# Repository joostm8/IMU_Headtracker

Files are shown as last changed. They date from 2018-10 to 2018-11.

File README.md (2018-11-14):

# IMU_Headtracker
## Preface
I wanted to use a headtracker to use in racing games such as Dirt Rally or RaceRoom Racing Experience. TrackIR is the best known tracker, but I couldn't really justify the cost. Having seen many other IMU-based headtracker projects, I figured this was a neat little project to work on in my spare time, since most of the heavy lifting work has already been done by other people:
- The IMU sensorfusion algorithm to translate accelerometer, gyroscope and magnetometer data into yaw, pitch and roll was made by Sebastian Madgwick and is available as C code:http://x-io.co.uk/open-source-imu-and-ahrs-algorithms/ .
- Opentrack is a project that can translate any joystick/gamepad information into freetrack data, used by games to do headtracking. Opentrack also provides centering support, and allows you to invert axis on-the-fly.

I really wanted no extra wiring, so I preferably wanted a Bluetooth dongle or something alike, such that I could treat the headtracker as a standalone little box.

## Hardware components
What was left to do for me was to use a microcontroller, an MPU and a Bluetooth dongle that runs a game controller HID profile, in order to relay the yaw, pitch and roll data to Opentrack in a standardised manner. I chose the following components:
- IMU: an Invensense MPU9250, this is the cheapest 9 DOF IMU I could readily find on ebay, it's usage is also thoroughly documented by Kris Winer on https://github.com/kriswiner/MPU9250 .
- Microcontroller: an Atmega328p running at 3.3V and 8MHz, more specifically as a Pro-Mini Arduino clone. It is a cheap microcontroller, readily available, comes with an Arduino bootloader so I don't need an AVR programmer and as documented in https://github.com/kriswiner/MPU9250 is just about able to run the MadgwickAHRS algorithm at an okay pace.
- Bluetooth module: an RN42 is the most easily available bluetooth module with HID gamepad support, but one can also flash the RN42 firmware on the even more broadly available HC-05 modules. Refer to this link for more information: https://mitxela.com/projects/bluetooth_hid_gamepad
- Power: a small 600 mAh LiPo battery and TC4056A charger board complete the list of required hardware.
- Two LEDs to give some feedback
- An ON-OFF switch (ON-ON also works)
- Two 680 ohm resistors to limit current to the LEDs

## Software components
I needed I2C communication to communicate with the MPU9250 (SPI is also possible), UART communication to communicate with the HC-05 and I needed to alter the MadgwickAHRS algorithm slightly.
- I2C communication is handled by an I2C library provided by Microchip: https://www.microchip.com/wwwAppNotes/AppNotes.aspx?appnote=en591794 (search for AN2480 in case the link doesn't work).
- The MadgwickAHRS algorithm normally expects to be run at a certain frequency, however the Atmega328p can't reliably run it at very high frequencies. Instead, I opted to alter the library, as demonstrated in this code from Michael Baker https://github.com/mikeshub/Pololu_Open_IMU, so it now calculates the time delta (dt) between the current start and the previous start of the code section of the AHRS algorithm, so it can basically run at the highest speed possible.
- UART to communicate with the HC-05: At 8 MHz clockspeed, 38400 baud is the highest baudrate that lies within the recommended clock error range, as stated in the Atmega328p manual. Since I need almost all cpu cycles to run the AHRS algorithm, I wrote a small UART transmit function that can handle one transmission in an unblocking fashion, such that I can transmit the yaw, roll and pitch to the Bluetooth dongle, while the AHRS algorithm continues executing.

## Wiring it all up:
A small table showing how I wired the components. Note that I relied on the LDO of the Pro-Mini to regulate the voltage for all parts. According to some datasheet on an Aliexpress like site, the part should provide at least 100 mA, whilst all components together will use approximately 60 mA, so this should be fine.

Note that I inserted an ON-OFF switch on the OUT+ line of the TC4056A, but this is not shown in the table.

**Note that the resistors aren't listed in the table, but PIN7 must be connected to the LED1 Anode through a 680 ohm resistor (likewise for PIN6 and LED2 Anode)!!**

| Pro-Mini | HC-05 | MPU9250 | TC4056A | LED1 | LED2 |
| --- | --- | --- | --- | --- | --- |
| SDA | | SDA | | | |
| SCL | | SCL | | | |
| TX | RX | | | | |
| RX | TX | | | | |
| PIN 7 | | | | Anode | |
| PIN 6 | | | | | Anode |
| RAW | | | OUT + | | |
| VCC (3.3V) | 3.3V in | 3.3V in | | | |
| GND | GND | GND | OUT - | Cathode | Cathode |

## 3D printable box
I've provided some STL files for a small 3D printable box that can mount the different components. The HC-05 I used was mounted on the standard blue breakout PCB, the MPU9250 is one of those modules mounted on the purple PCB. You'll have to stack the PCBs using pin headers, with a double layer of black spacers to achieve the correct spacing. On the HC-05, the TX, RX and GND pins match up, and on the MPU-9250 the SDA and SCL pins match up (granted you mount it **upside down**). Other pins can be connected with some servo wire. Note to self: provide a picture, that will be clearer.

## Some more remarks
### Application specific tips
- The Invense MPU9250 has built-in accelerometer calibration registers, however, even with their provided code (MPU Hardware Offset Registers Application Note) I could not get this to work correctly, therefore I did the accelerometer offsets in software. Gyroscope offset registers works fine.
- The more readily available RN42 manual has an incorrect specification of the joystick gamepad report format. Instead just use the format as described in https://mitxela.com/projects/bluetooth_hid_gamepad.
- The MadgwickAHRS algorithm does not care about the unit of the magnetometer and accelerometer readings, so don't waste computing time converting those readings to the correct unit. The gyroscope inputs do expect an input in radians per second.
- One might notice how there is some sign inversion happening on the input of the AHRS algorithm, that's because I mounted the MPU9250 upside down in the box.
- The LEDs help when starting the headtracker. When the LED on PIN7 goes on, you must place the headtracker on a flat surface, because it calculates the acceleromter and gyroscope offsets. When the LED on PIN6 goes on, you must wave the headtracker in a 8 shaped motion to calibrate the magnetometer (like you would do with your cellphone).
- The uploaded code is an Atmel Studio project, but a flashable hex file can be found in the Debug folder. One can flash with the command: `avrdude -c arduino -p atmega328p -P COM# -b 57800 -U flash:w:IMU_Headtracker.hex:i` Where `COM#`must be replaced with the id of your serial device (e.g. COM10), note that in linux this will be a `/dev/ttyS#`

### General debugging tips
If you want to attempt an IMU-headtracker project yourself, you might bump into some issues. In that case a debugger is your best friend, or if you don't have a debugger, a UART serial connection with some debug info is your best friend, however, do ensure you format your serial printouts correctly!
- an *int32_t* is defined as "signed long int" in stdint.h, so to print a correctly formatted string, use *%ld*
- float (*%f*) formatting is not supported by the AVR-libc *sprintf* function, therefore you must first use *dtostrf* , then use *strcat* to obtain a printout of a floating point number.

## License
The provided code is licensed under the GPLv3 license. The Microchip TWI library retains its own license.

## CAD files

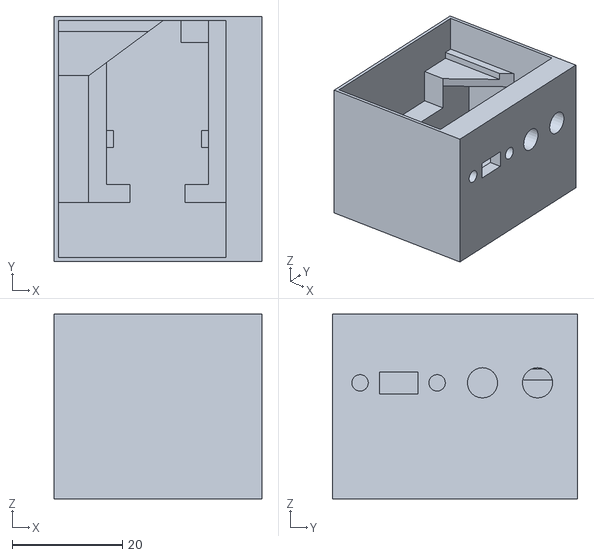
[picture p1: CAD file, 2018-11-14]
STL_files/headtracker_box.stl
37.8 x 44.6 x 33.6

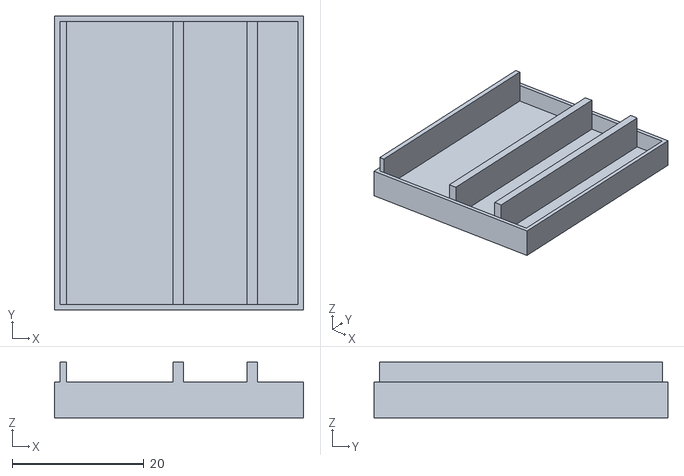
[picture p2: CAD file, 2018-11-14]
STL_files/headtracker_box_top_piece.stl
37.8 x 44.6 x 8.50

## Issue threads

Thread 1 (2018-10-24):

Add status LED functionality

joostm8, 2018-10-24:
With no serial monitor to view when you have to put down to device for calibration it would be nice to have some status LED's that indicate the calibration status instead. This way you also know when to start waving an 8 shape when calibrating the magnetometer.

joostm8, 2018-11-14:
Functionality added through pins 6 and 7

Closed 2018-11-14.

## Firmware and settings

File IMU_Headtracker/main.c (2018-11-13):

/*
 * IMU_Headtracker.c
 *
 * Created: 1/08/2018 20:43:46
 * Author : Joost
 *
 * IMU headtracker
 * Requires:
 * MPU9250
 * Atmega328p
 * rn42 (or hc05 flashed as rn42)
 * 
 */ 

/****************************************************************************
Macros
****************************************************************************/
#define MPU_9250_Addr 0b1101000 // 7 bit I2C address with AD0 pin to ground
#define AK8963_addr 0x0C // 7 bit magnetometer address
#define GYROSCOPE_RES_RPS 0.0005321125 // rps/lsb

// Timer 1 (16 bit) will be set to increment at rate of 1 µs
// this macro therefore allows for time deltas of up to 65 ms to be measured.
#define micros() TCNT1 

/****************************************************************************
Includes
****************************************************************************/
#include <avr/io.h>
#include <avr/interrupt.h>
#include <avr/sleep.h>
#include <util/delay.h>
#include <string.h>
#include <stdio.h>
#include <stdlib.h>
#include <stdint.h>
#include "TWI_Master.h"
#include "UART_transceiver.h"
#include "MadgwickAHRS.h"

/****************************************************************************
Variables
****************************************************************************/
static int16_t hard_iron_correction[3] = {0, 0, 0}; //x, y, z hard iron corrections, subtract from scaled measurements
// also see https://github.com/kriswiner/MPU6050/wiki/Simple-and-Effective-Magnetometer-Calibration
// precomputed magnetometer scale * soft iron
static float scale_times_soft_iron[3] = {0, 0, 0};
static uint8_t magneto_sens_adjust[3] = {0, 0, 0}; // x, y, z sens adjust values
static int16_t accelerometer_offset[3] = {0, 0, 0}; // accelerometer offsets to handle offsetting in SW.

// extern variables used in by MahonyAHRS
extern volatile float roll, pitch, yaw;
extern volatile float dt;	
extern volatile float q0, q1, q2, q3;

static uint8_t BT_command[8] = {0xFD, 0x06, 0x00, 0x00, 0x00, 0x00, 0x00, 0x00}; // BT command for HID game controller
static uint8_t send_BT_cmd = 0; // true/false when BT_cmd may be transmitted to BT chip

/****************************************************************************
  Function declarations
****************************************************************************/
void MPU_9250_initialise();
void calibrate_accelerometer();
void set_gyro_bias(int16_t*);
void calibrate_gyroscope();
void calibrate_magnetometer();
void get_magnetometer_scale();
uint8_t read_magnetometer(int16_t*);
void scale_magnetometer(float*);
void read_accelerometer_data(int16_t*);
void read_gyroscope_data(int16_t*);
void apply_magnetometer_scaling(int16_t*, float*);
void apply_accelerometer_offset(int16_t*);
void GPIO_setup_for_timing();
void GPIO_initialise();
void TIMER_setup();

/****************************************************************************
  Main code
****************************************************************************/

int main(void)
{
	
	// Start I2C interface using provided library by microchip
	// in TWI_Master.h, TWI_TWBR is set as 0x02, which yields 400kHz on 8MHz µC
	TWI_Master_Initialise();
		
	// Initialise UART at 38.4kbaud, the highest baudrate given F_CPU = 8 MHz
	UART_initialise();
	
	// Initialise LED GPIO
	GPIO_initialise();
	
	// enable global interrupts such that the I2C and UART interfaces can operate
	sei();

	_delay_ms(1000);
	
	// Initialise and calibrate MPU9250;
	MPU_9250_initialise();
	
	// Turn on pin 7, indicates to user to put the device on a flat surface
	PORTD |= 1 << PORTD7;
	
	_delay_ms(3000); // 3 second delay for user to put the device down.
	
	// Calibrate accelerometer;
	calibrate_accelerometer();
	
	// Calibrate gyroscope
	calibrate_gyroscope();
	
	// Turn off pin 7 LED
	PORTD &= ~(1 << PORTD7);
	// Turn on pin 6 LED, indicates to start waving 8 pattern
	PORTD |= 1 << PORTD6;
	
	_delay_ms(1000); // 1 sec delay for user response time.
	
	// calibrate magnetometer	
	get_magnetometer_scale();
	
	calibrate_magnetometer();
	
	// turn off LED, so user can stop waving
	PORTD &= ~(1 << PORTD6);

	//gyro is by now set to 1000 dps, which is ok
	//magneto is also set in +- 4g so we can move on to main program
	
	// Init Bluetooth controller (if needed)
	float magnetometer_data_float[3];
	float gyroscope_data_rps[3];
	int16_t magnetometer_data_raw[3];
	int16_t gyroscope_data_raw[3];
	int16_t accelerometer_data[3];
	TIMER_setup();
	GPIO_setup_for_timing();
	
	uint16_t start = micros();
	uint16_t stop = 0;
	uint8_t overflow = 0;
	
	// algorithm will run as fast as possible.
    while (1) 
    {
			PORTB |= 1<<PORTB1;
			read_gyroscope_data(gyroscope_data_raw);

			read_accelerometer_data(accelerometer_data);
			
			apply_accelerometer_offset(accelerometer_data);

			overflow = read_magnetometer(magnetometer_data_raw);
				
			//scale_magnetometer(magnetometer_data_gaus);
			if(!overflow){
				apply_magnetometer_scaling(magnetometer_data_raw, magnetometer_data_float);
			}
			else{
				magnetometer_data_float[0] = 0.0f;
				magnetometer_data_float[1] = 0.0f;
				magnetometer_data_float[2] = 0.0f;
			}
			
	
			//conversion to appropriate datatypes happens here
			gyroscope_data_rps[0] = (GYROSCOPE_RES_RPS * (float)gyroscope_data_raw[0]);
			gyroscope_data_rps[1] = (GYROSCOPE_RES_RPS * (float)gyroscope_data_raw[1]);
			gyroscope_data_rps[2] = (GYROSCOPE_RES_RPS * (float)gyroscope_data_raw[2]);
			
			// Note: for the Mahony algorithm: gx, gy, gz in radians/second
			// accelerometer data and magnetometer data can be in ANY calibrated unit (so even LSB)
			// magnetometer data must be scaled anyhow, but there is no point in converting to Tesla or Gauss
			
			stop = micros(); // get stop time before updating mahony
			dt = stop > start ? ((float)(stop - start))/1000000.0f : ((float)(UINT16_MAX - (start - stop)))/1000000.0f;
			start = micros(); // get start time for time delta for next calculation.
			
			MadgwickAHRSupdate( -gyroscope_data_rps[0],
								gyroscope_data_rps[1],
								-gyroscope_data_rps[2],
								(float)(-accelerometer_data[0]),
								(float)(accelerometer_data[1]),
								(float)(-accelerometer_data[2]),
								-magnetometer_data_float[1],
								magnetometer_data_float[0],
								magnetometer_data_float[2]);
					
			MadgwickAHRSupdateRollPitchYaw(); // move this within the BT transmit code perhaps since it's only needed there?.
			// update Bluetooth controller with axes info
			// lets start by just printing to serial :)

		// update BT module at approximately 60 Hz (can't find max supported rate, but at full blast, the BT module experienced crashes)
		if(send_BT_cmd){
			send_BT_cmd = 0;
			BT_command[2] = (int8_t)roll;	//X1
			BT_command[3] = (int8_t)pitch;	//Y1
			BT_command[4] = (int8_t)yaw;	//X2
			UART_tx((unsigned char*)BT_command, 8);
		}
			PORTB &= ~(1<<PORTB1);	
    }
	return 0;
}

/****************************************************************************
Call this function to initialise the MPU_9250, just selects clock src.
****************************************************************************/
void MPU_9250_initialise(){
	//configure clock source
	uint8_t write_cmd[3];
	write_cmd[0] = MPU_9250_Addr << 1; // write
	write_cmd[1] = 107; // PWR_MGMT_1
	write_cmd[2] = 0x80; // reset registers (so a reset of the MCU also cleans IMU calibrations)
	TWI_Start_Transceiver_With_Data(write_cmd, 3);
	
	write_cmd[1] = 107; // PWR_MGMT_1
	write_cmd[2] = 0x01; // auto select clock source;
	TWI_Start_Transceiver_With_Data(write_cmd, 3);
	
	//enable pass-through mode (also bypass mode) to access AK8963 (magneto)
	memset(write_cmd, 0, 3);
	write_cmd[0] = MPU_9250_Addr << 1; // write
	write_cmd[1] = 55; // INT_PIN_CFG
	write_cmd[2] = 0x02; // BYPASS_EN
	TWI_Start_Transceiver_With_Data(write_cmd, 3);
}

/****************************************************************************
Call this function to calibrate the accelerometer.
It calculates average offsets when the device is on a flat surface, and
writes these offsets back to the device.
****************************************************************************/
void calibrate_accelerometer(){
	// Set accelerometer range to +/- 4g since I expect this range to be used
	uint8_t write_cmd[3];
	write_cmd[0] = MPU_9250_Addr << 1; // write
	write_cmd[1] = 28; // Accelerometer configuration register
	write_cmd[2] = 0b00001000; // set ACCEL_FS_SEL to 01 or +/- 4g, DLPC_CFG to 0 (250 Hz)
	TWI_Start_Transceiver_With_Data(write_cmd, 3);
	
	// take 1024 samples to average
	int32_t sum[3] = {0, 0, 0};
	int16_t accelerometer_data[3] = {0, 0, 0};
	for(uint16_t i = 0; i < 2048; ++i){
		read_accelerometer_data(accelerometer_data);
		
		//accumulate immediately to limit RAM usage
		sum[0] += accelerometer_data[0];
		sum[1] += accelerometer_data[1];
		sum[2] += accelerometer_data[2];
		
		//update rate is 1kHz with default settings
		_delay_ms(1.1);
	}
	
	// int32_t is a signed long int, so when formatting in formatting functions
	// one needs to use %ld... Finally solved.
	sum[0] = (sum[0])/2048;
	sum[1] = (sum[1])/2048;
	sum[2] = (sum[2])/2048;
	
	//take averages, sign inversion is done when setting the biases
	//note that integer accuracy loss isn't bad because
	//the values are stored as integers on the MPU anyway.
	accelerometer_offset[0] = sum[0]; //x
	accelerometer_offset[1] = sum[1]; //y
	accelerometer_offset[2] = sum[2]; //z, from which you must subtract/add 2048 (1g) since z axis measures 1g
	if(accelerometer_offset[2] > 0)
		accelerometer_offset[2] -= 8192; //if z value is positive, subtract 1g (8192 LSB);
	else
		accelerometer_offset[2] += 8192; //otherwise, add 1g (8192 LSB);
	// note that the if else above does not expect more than 1g of offset (shouldn't be the case)
}

/****************************************************************************
Applies accelerometer offsets on data
****************************************************************************/
void apply_accelerometer_offset(int16_t* accel_data){
	accel_data[0] -= accelerometer_offset[0];
	accel_data[1] -= accelerometer_offset[1];
	accel_data[2] -= accelerometer_offset[2];
}

/****************************************************************************
Reads accelerometer data, assumes data is being collected continuously
****************************************************************************/
void read_accelerometer_data(int16_t* accel_data){
	uint8_t write_cmd[3];
	uint8_t read_cmd[7];
	write_cmd[0] = MPU_9250_Addr << 1; // write
	write_cmd[1] = 59; // ACCEL_XOUT_H;	
	read_cmd[0] = MPU_9250_Addr << 1 | 1; // read
	TWI_Start_Transceiver_With_Data(write_cmd, 2);
	TWI_Start_Transceiver_With_Data(read_cmd, 7);
	TWI_Get_Data_From_Transceiver(read_cmd, 7);
	accel_data[0] = read_cmd[1] << 8 | read_cmd[2];
	accel_data[1] = read_cmd[3] << 8 | read_cmd[4];
	accel_data[2] = read_cmd[5] << 8 | read_cmd[6];
}

/****************************************************************************
Call this function to calibrate the gyroscope.
It calculates average offsets when the device is on a flat surface, and
writes these offsets back to the device.
****************************************************************************/
void calibrate_gyroscope(){
	// Set gyroscope range to 1000 dps since offset is stored in that format
	uint8_t write_cmd[3];
	write_cmd[0] = MPU_9250_Addr << 1; // write
	write_cmd[1] = 27; // Gyro configuration register
	write_cmd[2] = 0b00010000; // set GYRO_FS_SEL to 10 or 1000 dps;
	TWI_Start_Transceiver_With_Data(write_cmd, 3);
	
	int32_t sum[3] = {0, 0, 0};
	int16_t gyro_data[3];
	// take 1024 samples to average
	for(uint16_t i = 0; i < 2048; ++i){
		//accumulate immediately to limit RAM usage
		read_gyroscope_data(gyro_data);
		sum[0] += gyro_data[0];
		sum[1] += gyro_data[1];
		sum[2] += gyro_data[2];	
		
		//update rate is 8kHz with default settings
		_delay_us(125);
	}
	
	//take averages, sign inversion is done when setting the biases
	//note that integer accuracy loss isn't bad because
	//the values are stored as integers on the MPU anyway.
	int16_t gyro_bias[3];
	gyro_bias[0] = (int16_t)(sum[0]/2048); //x
	gyro_bias[1] = (int16_t)(sum[1]/2048); //y
	gyro_bias[2] = (int16_t)(sum[2]/2048); //z
	
	set_gyro_bias(gyro_bias);
}

/****************************************************************************
This function reads gyroscope data.
It assumes data is being sampled
****************************************************************************/
void read_gyroscope_data(int16_t* gyro_data){
	uint8_t write_cmd[2];
	uint8_t read_cmd[7];
	write_cmd[0] = MPU_9250_Addr << 1; // write
	write_cmd[1] = 67; // GYRO_XOUT_H;
	read_cmd[0] = MPU_9250_Addr << 1 | 1; // read
	TWI_Start_Transceiver_With_Data(write_cmd, 2);
	TWI_Start_Transceiver_With_Data(read_cmd, 7);
	TWI_Get_Data_From_Transceiver(read_cmd, 7);
	gyro_data[0] = read_cmd[1] << 8 | read_cmd[2];
	gyro_data[1] = read_cmd[3] << 8 | read_cmd[4];
	gyro_data[2] = read_cmd[5] << 8 | read_cmd[6];
}

/****************************************************************************
This function writes gyroscope biases to the offset registers.
1000 dps format
****************************************************************************/
void set_gyro_bias(int16_t* gyro_bias){
	uint8_t data[6] = {0, 0, 0, 0, 0, 0};
		
	for(uint8_t i = 0 ; i < 3 ; ++i) {
		gyro_bias[i] = (-gyro_bias[i]);
	}
	
	data[0] = (gyro_bias[0] >> 8) & 0xff;
	data[1] = (gyro_bias[0]) & 0xff;
	data[2] = (gyro_bias[1] >> 8) & 0xff;
	data[3] = (gyro_bias[1]) & 0xff;
	data[4] = (gyro_bias[2] >> 8) & 0xff;
	data[5] = (gyro_bias[2]) & 0xff;
	
	uint8_t cmd[8];
	cmd[0] = MPU_9250_Addr << 1; //Write
	cmd[1] = 19; //XG_OFFSET_H;
	memcpy(&cmd[2], data, 6);// copy data over
	TWI_Start_Transceiver_With_Data(cmd, 8);
}

/****************************************************************************
This function gets the hard and soft iron offsets used to correct magnetometer
values.
It assumes the magneto is in power down mode at the start.
****************************************************************************/
void calibrate_magnetometer(){
	// set magnetometer to 16 bit continuous 100 Hz mode.
	uint8_t write_cmd[3];
	write_cmd[0] = AK8963_addr << 1; //Write
	write_cmd[1] = 0x0A; // CNTL1
	write_cmd[2] = 0x16; // 16 bit, Continuous 2 (100 Hz)
	TWI_Start_Transceiver_With_Data(write_cmd, 3);
	//The device is now continuously measuring the data.
	
	// at 100 Hz, a new sample is available every 10 ms.
	int16_t magneto_data[3];
	int16_t max[3] = {-32768, -32768, -32768};
	int16_t min[3] = {32767, 32767, 32767};
	// first goal is to determine the max and min x, y, z values
	for(uint16_t i = 0; i < 2048; ++i){
		
		read_magnetometer(magneto_data);
				
		for(uint8_t j = 0; j < 3; ++j){
			if(magneto_data[j] < min[j])
				min[j] = magneto_data[j];
			if(magneto_data[j] > max[j])
				max[j] = magneto_data[j];
		}
		_delay_ms(10);
	}
		
	// now calculate raw hard iron corrections:
	hard_iron_correction[0] = (max[0] + min[0])/2;
	hard_iron_correction[1] = (max[1] + min[1])/2;
	hard_iron_correction[2] = (max[2] + min[2])/2;
	
	// calculate soft iron correction (at once in float since I must scale them afterwards)
	float soft_iron_raw[3];
	soft_iron_raw[0] = (float)((max[0] - min[0])/2);
	soft_iron_raw[1] = (float)((max[1] - min[1])/2);
	soft_iron_raw[2] = (float)((max[2] - min[2])/2);

	// scale soft iron
	// not reallt needed to scale it here, could save 2 floating point multiplications
	float* soft_iron_scaled = soft_iron_raw;
	scale_magnetometer(soft_iron_scaled);
	
	// scaling only needs to be done here on avg_rad
	float avg_rad = soft_iron_scaled[0] + soft_iron_scaled[1] + soft_iron_scaled[2];
	avg_rad /= 3.0;
	
	float soft_iron_correction[3] = {0, 0, 0};
	soft_iron_correction[0] = avg_rad/soft_iron_scaled[0];
	soft_iron_correction[1] = avg_rad/soft_iron_scaled[1];
	soft_iron_correction[2] = avg_rad/soft_iron_scaled[2];
	
	scale_times_soft_iron[0] = (((float)magneto_sens_adjust[0] - 128.0) / 256.0 + 1.0) * soft_iron_correction[0];
	scale_times_soft_iron[1] = (((float)magneto_sens_adjust[1] - 128.0) / 256.0 + 1.0) * soft_iron_correction[1];
	scale_times_soft_iron[2] = (((float)magneto_sens_adjust[2] - 128.0) / 256.0 + 1.0) * soft_iron_correction[2];
}

/****************************************************************************
This function scales magnetometer readings with the scale adjustment values.
scaling happens in place
****************************************************************************/
void scale_magnetometer(float* magneto_data){
	magneto_data[0] = magneto_data[0] * (((float)magneto_sens_adjust[0] - 128) * 0.5 / 128.0 + 1.0);
	magneto_data[1] = magneto_data[1] * (((float)magneto_sens_adjust[1] - 128) * 0.5 / 128.0 + 1.0);
	magneto_data[2] = magneto_data[2] * (((float)magneto_sens_adjust[2] - 128) * 0.5 / 128.0 + 1.0);
}

/****************************************************************************
This function reads the magnetometer data. parameter is empty array of x, y, z
The function assumes the magnetometer is in a measurement mode

returns: 1 when magnetic overflow occurred
		 0 when no overflow occurred
****************************************************************************/
uint8_t read_magnetometer(int16_t* magneto_data){
	
	uint8_t write_cmd[2];
	write_cmd[0] = AK8963_addr << 1; //Write
	write_cmd[1] = 0x03; // HXL
	uint8_t read_cmd[8]; // one must also read status 2 register as it denotes the end of a read
	// further it contains the magnetic sensor overflow bit, which must be checked to know if algorithm
	// may use the magnetometer readings or not.
	read_cmd[0] = AK8963_addr << 1 | 1; // Read
			
	TWI_Start_Transceiver_With_Data(write_cmd, 2);
	TWI_Start_Transceiver_With_Data(read_cmd, 8);
	TWI_Get_Data_From_Transceiver(read_cmd, 8);
	
	magneto_data[0] = read_cmd[2] << 8 | read_cmd[1];
	magneto_data[1] = read_cmd[4] << 8 | read_cmd[3];
	magneto_data[2] = read_cmd[6] << 8 | read_cmd[5];
	
	// magneto data[7] is status reg 2
	return (magneto_data[7] & 0x08) > 0;
}

/****************************************************************************
This function gets the magnetometer scale adjustment, used later on in the
program.
It assumes the magneto is in power down mode at the start.
****************************************************************************/
void get_magnetometer_scale(){
	//First set magnetometer in Fuse ROM Access mode
	uint8_t write_cmd[3];
	write_cmd[0] = AK8963_addr << 1; //Write
	write_cmd[1] = 0x0A; // CNTL1
	write_cmd[2] = 0x0F; // Fuse ROM Access Mode
	TWI_Start_Transceiver_With_Data(write_cmd, 3);
	//The device is now in Fuse ROM Access Mode
	//Read the magneto sens adjust (int8)
	memset(write_cmd, 0, 3);
	write_cmd[0] = AK8963_addr << 1; //Write
	write_cmd[1] = 0x10; // X-axis sens adjust value
	uint8_t read_cmd[4];
	read_cmd[0] = AK8963_addr << 1 | 1; //Read
	TWI_Start_Transceiver_With_Data(write_cmd, 2);
	TWI_Start_Transceiver_With_Data(read_cmd, 4);
	TWI_Get_Data_From_Transceiver(read_cmd, 4);
	
	magneto_sens_adjust[0] = read_cmd[1];
	magneto_sens_adjust[1] = read_cmd[2];
	magneto_sens_adjust[2] = read_cmd[3];

	//Finally put the magnetometer back in power down mode
	memset(write_cmd, 0, 3);
	write_cmd[0] = AK8963_addr << 1; //Write
	write_cmd[1] = 0x0A; // CNTL1
	write_cmd[2] = 0x00; // Power Down Mode
	TWI_Start_Transceiver_With_Data(write_cmd, 3);
	// datasheet asks to wait 100 µs before transitioning to other modes,
	// delay here to be sure this is respected
	_delay_us(100);
}

/****************************************************************************
Applies  hard iron, soft iron and scaling correction on magnetometer readings.

normal fomula is:

data in Gauss (or Tesla) = (raw * scale - hard_iron * scale) * soft_iron * Res
with raw in LSB, hard_iron in lsb, scale the scalar scale factor per datasheet
soft iron as a scalar and Res either in Gauss/LSB or Tesla/LSB

Since we don't need to convert to Gauss or Tesla and we can bring scale upfront:
data in LSB = (raw - hard_iron) * scale * soft_iron
scale * soft_iron can be computed upfront and stored in variable scale_times_soft_iron
****************************************************************************/
void apply_magnetometer_scaling(int16_t* data_raw, float* data_calibrated){
	data_calibrated[0] = (data_raw[0] - hard_iron_correction[0]) * scale_times_soft_iron[0];
	data_calibrated[1] = (data_raw[1] - hard_iron_correction[1]) * scale_times_soft_iron[1];
	data_calibrated[2] = (data_raw[2] - hard_iron_correction[2]) * scale_times_soft_iron[2];
}

/****************************************************************************
Sets up TIMER1 (16 bits) in normal mode at 1 µs steps
****************************************************************************/
void TIMER_setup(){
	// setup in normal mode, but do enable OCR1A and COMPA interrupt
	OCR1A = 16665;
	TIFR1 = 0x02; // clear any pending interrupts first
	TIMSK1 |= 0x02; // enable OCIE1A
	TCCR1B |= 0x02; // select /8 prescaler and start timer
}

/****************************************************************************
GPIO pin for debug timing purposes.
****************************************************************************/
void GPIO_setup_for_timing(){
	DDRB |= 1 << PORTB1;	
}

/****************************************************************************
Setup pins 6 and 7 for LED output
****************************************************************************/
void GPIO_initialise(){
	DDRD |= (1 << PORTD7) | (1 << PORTD6);
}
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

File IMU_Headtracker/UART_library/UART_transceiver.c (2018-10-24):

/*
 * UART_transceiver.c
 *
 * Created: 15/10/2018 15:19:49
 *  Author: Joost
 */ 

/****************************************************************************
Includes
****************************************************************************/
#include <avr/io.h>
#include <avr/interrupt.h>
#include <avr/sleep.h>
#include <string.h>
#include <util/delay.h>
#include "UART_transceiver.h"

/****************************************************************************
Macros
****************************************************************************/
#define UART_tx_enable()	UCSR0B |= 1<<TXEN0
#define UART_rx_enable()	UCSR0B |= 1<<RXEN0
#define UART_rx_disable()	UCSR0B &= ~(1<<RXEN0)
#define UART_enable()		UCSR0B |= 1<<TXEN0 | 1<<RXEN0

/****************************************************************************
Variables
****************************************************************************/
static uint32_t tx_length = 0;
static uint8_t tx_buffer[100]; // buffer for transmissions
static uint8_t* rx_buffer = 0;
typedef enum uart_state {
	waiting,
	tx,
	rx,
	tx_rx
} uart_state;
static volatile uart_state state = waiting;
static volatile uint32_t tx_cnt = 0;
static volatile uint32_t rx_cnt = 0;
static const unsigned char rx_terminator[2] = "\r\n";

/****************************************************************************
Call this function to set up the UART to its initial standby state.
Remember to enable interrupts from the main application after initializing the UART.
****************************************************************************/
void UART_initialise(){
	//initial UART config
	UCSR0A &= !(1<<U2X0);// clear this bit, not properly cleaned up from bootloader
	UCSR0B = 1<<RXCIE0 | 1<<TXCIE0 | 0<<UDRIE0 | 0<<UCSZ02;
	UCSR0C = 1<<UCSZ01 | 1<<UCSZ00;
	UBRR0 = 12;
	UART_tx_enable();
}

/****************************************************************************
Call this function to transmit a byte stream over the UART interface.
The function is blocking, but power optimized.

	tx_data_ptr	pointer to byte stream
	length		number of bytes to transmit
****************************************************************************/
uint8_t UART_tx(unsigned char* tx_data_ptr, uint32_t length){
	while(state != waiting){
		//loop while waiting for new command
	}
	if(state == waiting){
		if(length > 0){
			state = tx;
			memcpy(tx_buffer, tx_data_ptr, length);
			tx_length = length;
			tx_cnt = 0; //reset txCnt to 0
			UDR0 = *tx_buffer; //load first byte
			UCSR0B |= 1<<UDRIE0; 
			//enable interrupt, ISR takes over from here
			/*
			while(state == tx){
				cli();
				sleep_enable();
				sei();
				sleep_cpu();
				sleep_disable();
			}
			*/
			// above commented out to make at least 1 write non blocking
			return 1;
		}
		return 0;
	}
	return 0;	
}

/****************************************************************************
Call this function to transmit a byte stream over the UART interface.
The response is buffered in rx_data_ptr, and assumes /cr/lf to be the
termination of the response. The function is blocking, but power optimized.

	tx_data_ptr	pointer to transmit byte stream
	rx_data_ptr pointer to reception buffer in which response is stored
				make sure to leave room for the \0 terminator.
	length		number of bytes to transmit
****************************************************************************/
uint8_t UART_tx_rx(unsigned char* tx_data_ptr, unsigned char* rx_data_ptr, uint32_t length){
	if(state == waiting){
		if(length > 0){
			state = tx;
			tx_length = length;
			tx_cnt = 0; // reset tx_cnt to 0
			rx_cnt = 0; // reset rx_cnt to 0
			rx_buffer = rx_data_ptr;
			UART_enable();
			UDR0 = *tx_buffer; //load first byte
			UCSR0B |= 1<<UDRIE0;
			//enable interrupt, ISR takes over from here
			while(state != waiting){
				cli();
				sleep_enable();
				sei();
				sleep_cpu();
				sleep_disable();
			}
			return 1;
		}
		return 0;
	}
	return 0;
}

/****************************************************************************
Call this function to transmit a byte stream over the UART interface.
The response is buffered in rx_data_ptr, and assumes /cr/lf to be the
termination of the response. A timeout can be specified in milliseconds.
The function is blocking, and not power optimized in order to facilitate
the timeout without timer. The timeout is not entirely accurate.

	tx_data_ptr	pointer to transmit byte stream
	rx_data_ptr pointer to reception buffer in which response is stored
				make sure to leave room for the \0 terminator.
	length		number of bytes to transmit3
	timeout		timeout after which to stop reception, in ms
****************************************************************************/
uint8_t UART_tx_rx_w_timeout(unsigned char* tx_data_ptr, unsigned char* rx_data_ptr, uint32_t length, uint32_t timeout){
	if(state == waiting){
		if(length > 0){
			int timeout_cnt = 0;
			state = tx;
			tx_length = length;
			tx_cnt = 0; // reset tx_cnt to 0
			rx_cnt = 0; // reset rx_cnt to 0
			rx_buffer = rx_data_ptr;
			UART_enable();
			UDR0 = *tx_buffer; //load first byte
			UCSR0B |= 1<<UDRIE0;
			//enable interrupt, ISR takes over from here
			while(state != waiting && timeout_cnt < timeout){
				++timeout_cnt;
				_delay_ms(1);
			}
			if(timeout_cnt >= timeout){
				//in this case return 0, reset states and set uart back to waiting
				UCSR0B &= ~(1<<UDRIE0); // disable transmit interrupt in case timeout < transmit time
				UART_rx_disable();
				state = waiting;
				return 0;
			}
			// otherwise just return 1;
			return 1;
		}
		return 0;
	}
	return 0;	
}

ISR(USART_RX_vect){
	rx_buffer[rx_cnt] = UDR0;
	if(rx_cnt > 0)
		if(memcmp(&rx_buffer[rx_cnt-1], rx_terminator, 2)){
			// In this case, we just append \0 and disable the UART reception, then set correct state
			rx_buffer[rx_cnt + 1] = '\0';
			if(state == tx_rx)
				state = tx;
			else
				state = waiting;
			UART_rx_disable();
		}
	++rx_cnt;
}

ISR(USART_UDRE_vect){
	++tx_cnt;// increment txCnt (since the byte has been loaded in transmitter
	if(tx_cnt < tx_length){
		UDR0 = tx_buffer[tx_cnt];
		//this clears the interrupt flag automatically.
	}
	else{
		//disable UDRE interrupt
		UCSR0B &= ~(1<<UDRIE0);
		//once last byte has left, TX_vect should trigger, updating the transmit state
	}
}

ISR(USART_TX_vect){
	// set state to only rx of coming from tx_rx
	// alternatively, when coming from tx, go back to waiting.
	if(state == tx_rx)
		state = rx;
	else
		state = waiting;
}

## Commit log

2018-09-12 Added configuration of UART
2018-09-12 Added uart transmission funcion
2018-10-15 UART lilbrary
    Created samll library with the UART functions I will need later on.
2018-10-16 Added accelerometer calibration code
    Added accelerometer calibration code
2018-10-16 Added gyroscope calibration
    Added gyroscope calibration
2018-10-17 Debugging as to why it doesn't work
    int32_t divisoin is broken apparantely?
    [UART_transceiver.c, main.cpp]
2018-10-17 Figured out the problem
    For future reference int32_t must be formatted as %ld since its a long for avr devices
    [main.cpp]
2018-10-18 Fixed incorrect conversion from LSB to other unit
    Added many more debug prints
    [main.cpp]
2018-10-23 Tested some more concerning Y axis
    Calibration of accel seems to be the problem. As noted in KrisWinner's git, most likely seems to be due to the temperature compensation bit which isn't really documented. Although I implemented the calibration as documented in the Ivensense AN, I will just resort to software calibration for the accelerometer, since without hardware calibration everything seems to be fine.
    [main.cpp]
2018-10-24 Reverted back to regular C project from C++
    [main.c]
2018-10-24 Working at last!
    everything works, however much code cleanup remains to be done.
    Will test effect of LPF on IMU readings as well as possibility to use 57600 baud instead of 38400 (57600 is technically slightly over the allowed clock drift...)
    [UART_transceiver.c, main.c]
2018-10-24 Added check for magnetometer overflow
    The magnetometer also reports if readings are incorrect (overflow). In that case update the mahony algorithm with 0 mX values to prevent incorrect operation.
    [main.c]
2018-10-24 Update to MadgwickAHRS
    Changed the AHRS algorithm to the MadgwickAHRS, which has fixed the yaw drift I noticed when using Mahony :)
    [main.c]
2018-10-24 Update to code that transmits over BT
    Updated the output of the device such that the axes are transmitted to the BT module, which acts as USB HID gamepad
2018-11-12 Added LED functionality for calibration
2018-11-12 Cleanup
    - removed debug print statements from code
    - updated functions to void when return value was not used
    - removed unused variables and functions
2018-11-13 Final commit
    - Updated pitch to use full range
    - updated axis direction, due to changed orientation of IMU
    - Added clipping prevention on pitch
    [main.c]
2018-11-14 Added STL files for 3D printable box
    [headtracker_box.stl, headtracker_box_top_piece.stl]
